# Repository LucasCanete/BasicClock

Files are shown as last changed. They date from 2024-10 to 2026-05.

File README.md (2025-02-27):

# BasicClock
Small atmega328p-based Clock displays the time, the temperature and humidity of the room.

## Table of Contents
1. [About the Project](#about-the-project)
2. [Project Status](#project-status)
3. [Getting Started](#getting-started)

## About the Project
Every Christmas I have to think hard what to give as a gift to my friends. As the Maker i am i decided to develop a device i could always give as a gift in Birthdays or Christmas when i dont come with any better idea. The device is a simple Clock with a big display and three buttons. The Clock lets the user see the time, temperature and humidity of the room. Additionally, the user can configure the time in case time changes or the person moves to a different timezone.

Besides from all this, i just wanted to try program different sensors with the Atmega328p using C++. I found it very convenient with the OOP so i might keep using it in the future.

Features:
- Visualization of current date, hour, temperature and humidity
- Configuration of date and hour
- USB-C port for UART communication
- Small design for being portable

## Project Status
Project is currently under development. Next Steps are the following:
- [x] Order Board from JLCPCB
- [ ] Order Stencil (i forgot it the first time)
- [ ] Solder SMD Components
- [ ] Test BME280
- [ ] Test RTC
- [ ] Test USB-C UART Communication
- [ ] Write driver for Display
- [ ] Finish writing the firmware

## Getting Started
Coming soon

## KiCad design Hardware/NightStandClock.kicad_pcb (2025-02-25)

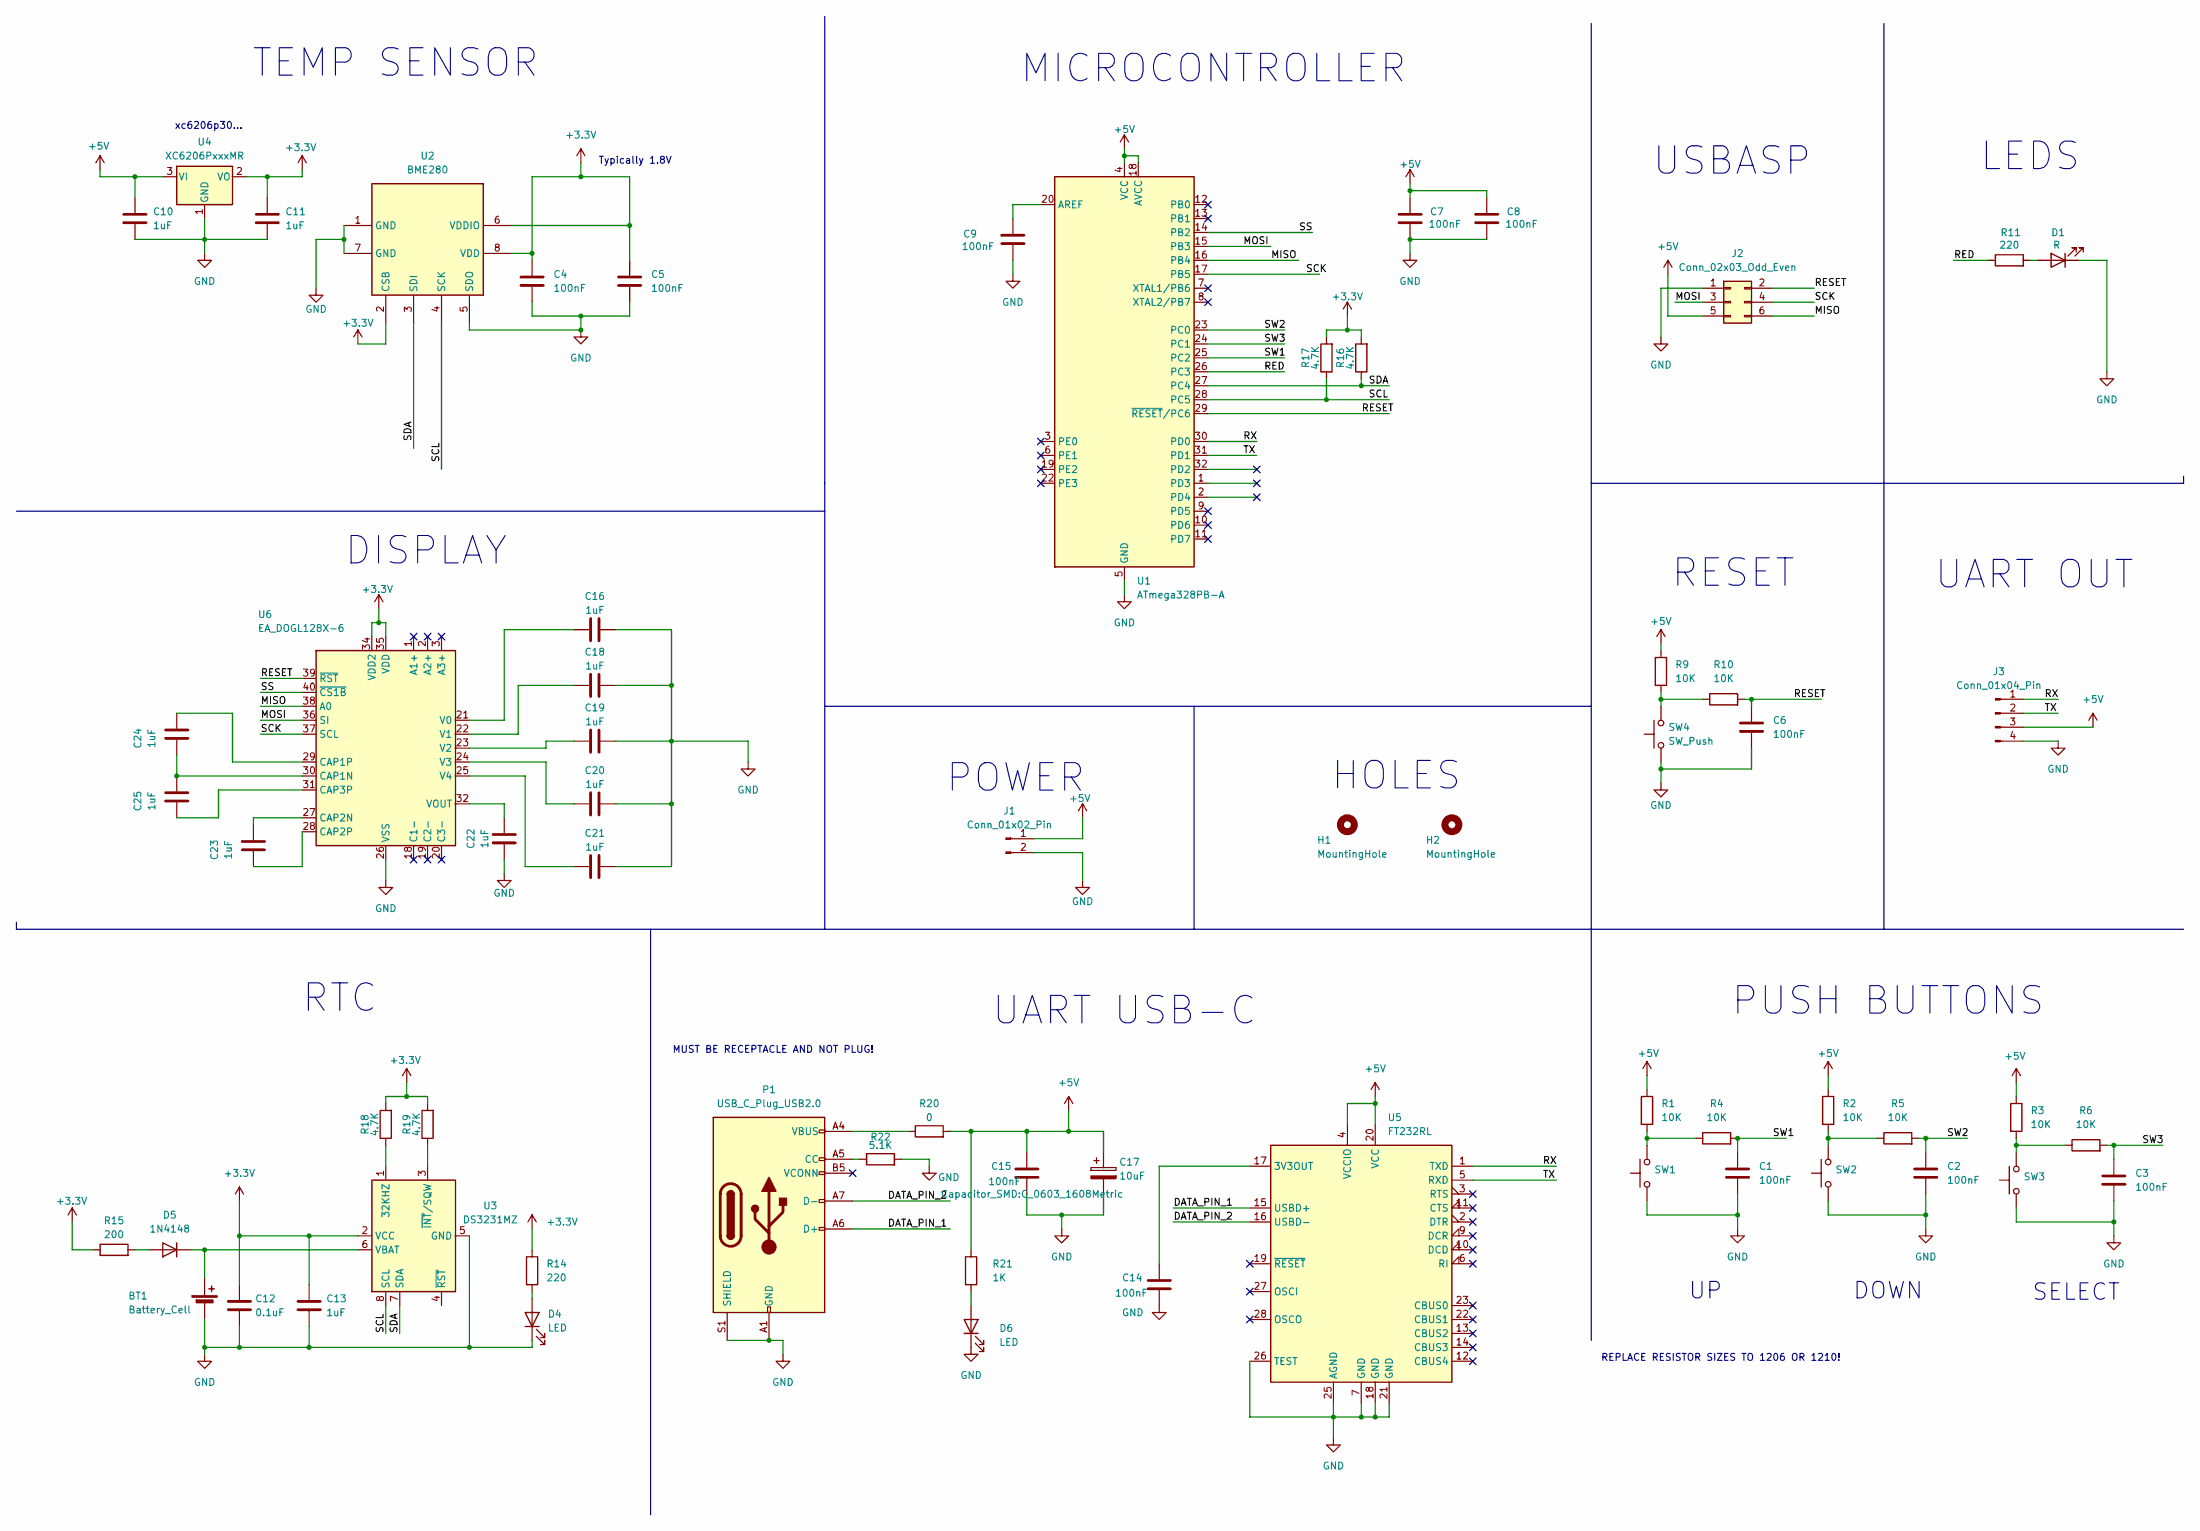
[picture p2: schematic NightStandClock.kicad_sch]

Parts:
BT1: Battery_Cell; BatteryHolder_MYOUNG_BS-07-A1BJ001_CR2032
C1, C2, C3, C4, C5, C6, C7, C8, C9, C14, C15: 100nF; C_0603_1608Metric
C10, C11, C13, C16, C18, C19, C20, C21, C22, C23, C24, C25: 1uF; C_0603_1608Metric
C12: 0.1uF; C_0603_1608Metric
C17: 10uF; CP_Radial_D4.0mm_P2.00mm
D1: R; LED_0603_1608Metric
D4, D6: LED; LED_0603_1608Metric
D5: 1N4148; D_0603_1608Metric
H1, H2: MountingHole; MountingHole_2.1mm
J1: Conn_01x02_Pin; JST_XH_B2B-XH-A_1x02_P2.50mm_Vertical
J2: Conn_02x03_Odd_Even; PinSocket_2x03_P2.54mm_Vertical
J3: Conn_01x04_Pin; PinHeader_1x04_P2.54mm_Vertical
P1: USB_C_Plug_USB2.0; USB_C_Receptacle_GCT_USB4105-xx-A_16P_TopMnt_Horizontal
R1, R2, R3, R4, R5, R6, R9, R10: 10K; R_0603_1608Metric
R11, R14: 220; R_0603_1608Metric
R15: 200; R_0603_1608Metric
R16, R17, R18, R19: 4.7K; R_0603_1608Metric
R20: 0; R_0603_1608Metric
R21: 1K; R_0603_1608Metric
R22: 5.1K; R_0603_1608Metric
SW1, SW2, SW3: SW_PUSH_1P1T_6x3.5mm_H4.3_APEM_MJTP1243
SW4: SW_Push; SW_PUSH_1P1T_6x3.5mm_H4.3_APEM_MJTP1243
U1: ATmega328PB-A; TQFP-32_7x7mm_P0.8mm
U2: BME280; Bosch_LGA-8_2.5x2.5mm_P0.65mm_ClockwisePinNumbering
U3: DS3231MZ; SOIC-8_3.9x4.9mm_P1.27mm
U4: XC6206PxxxMR; SOT-23
U5: FT232RL; SSOP-28_5.3x10.2mm_P0.65mm
U6: EA_DOGL128X-6; EA_DOGL128-6

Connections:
+3.3V: C4.1, C5.1, C11.1, C12.1, C13.1, R14.1, R15.1, R16.2, R17.2, R18.2, R19.2, U2.2 (CSB), U2.6 (VDDIO), U2.8 (VDD), U3.2 (VCC), U4.2 (VO), U6.34 (VDD2), U6.35 (VDD)
+5V: C7.1, C8.1, C10.1, C15.1, C17.1, J1.1, J2.5, J3.3, R1.1, R2.1, R3.1, R9.1, R20.2, R21.1, U1.4 (VCC), U1.18 (AVCC), U4.3 (VI), U5.4 (VCCIO), U5.20 (VCC)
/DATA_PIN_1: P1.A6 (D+), U5.15 (USBD+)
/DATA_PIN_2: P1.A7 (D-), U5.16 (USBD-)
/MISO: J2.6, U1.16 (PB4), U6.38 (A0)
/MOSI: J2.3, U1.15 (PB3), U6.36 (SI)
/RED: R11.1, U1.26 (PC3)
/RESET: C6.1, J2.2, R10.2, U1.29 (~RESET/PC6), U6.39 (~RST)
/RX: J3.1, U1.30 (PD0), U5.1 (TXD)
/SCK: J2.4, U1.17 (PB5), U6.37 (SCL)
/SCL: R17.1, U1.28 (PC5), U2.4 (SCK), U3.8 (SCL)
/SDA: R16.1, U1.27 (PC4), U2.3 (SDI), U3.7 (SDA)
/SS: U1.14 (PB2), U6.40 (~CS1B)
/SW1: C1.1, R4.2, U1.25 (PC2)
/SW2: C2.1, R5.2, U1.23 (PC0)
/SW3: C3.1, R6.2, U1.24 (PC1)
/TX: J3.2, U1.31 (PD1), U5.5 (RXD)
GND: BT1.2 (-), C1.2, C2.2, C3.2, C4.2, C5.2, C6.2, C7.2, C8.2, C9.2, C10.2, C11.2, C12.2, C13.2, C14.2, C15.2, C16.2, C17.2, C18.2, C19.2, C20.2, C21.2, C22.1, D1.1 (K), D4.1 (K), D6.1 (K), J1.2, J2.1, J3.4, P1.A1 (GND), P1.A12 (GND), P1.B1 (GND), P1.B12 (GND), P1.S1 (SHIELD), R22.2, SW1.1, SW2.1, SW3.1, SW4.1, U1.5 (GND), U1.21 (GND), U2.1 (GND), U2.5 (SDO), U2.7 (GND), U3.5 (GND), U4.1 (GND), U5.7 (GND), U5.18 (GND), U5.21 (GND), U5.25 (AGND), U5.26 (TEST), U6.26 (VSS), U6.33 (VSS)
unnamed: BT1.1 (+), D5.1 (K), U3.6 (VBAT)
unnamed: D1.2 (A), R11.2
unnamed: D4.2 (A), R14.2
unnamed: D5.2 (A), R15.2
unnamed: D6.2 (A), R21.2
unnamed: P1.A5 (CC), R22.1
unnamed: P1.A4 (VBUS), P1.A9 (VBUS), P1.B4 (VBUS), P1.B9 (VBUS), R20.1
unnamed: R1.2, R4.1, SW1.2
unnamed: R2.2, R5.1, SW2.2
unnamed: R3.2, R6.1, SW3.2
unnamed: R9.2, R10.1, SW4.2
unnamed: C9.1, U1.20 (AREF)
unnamed: R18.1, U3.1 (32KHZ)
unnamed: R19.1, U3.3 (~INT/SQW)
unnamed: C14.1, U5.17 (3V3OUT)
unnamed: C24.1, C25.2, U6.30 (CAP1N)
unnamed: C24.2, U6.29 (CAP1P)
unnamed: C23.2, U6.27 (CAP2N)
unnamed: C23.1, U6.28 (CAP2P)
unnamed: C25.1, U6.31 (CAP3P)
unnamed: C16.1, U6.21 (V0)
unnamed: C18.1, U6.22 (V1)
unnamed: C19.1, U6.23 (V2)
unnamed: C20.1, U6.24 (V3)
unnamed: C21.1, U6.25 (V4)
unnamed: C22.2, U6.32 (VOUT)

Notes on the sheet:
RESET
DISPLAY
REPLACE RESISTOR SIZES TO 1206 OR 1210!
Typically 1.8V
HOLES
UART USB-C
POWER
xc6206p30...
UART OUT
PUSH BUTTONS
DOWN
MUST BE RECEPTACLE AND NOT PLUG!
MICROCONTROLLER
TEMP SENSOR
SELECT
LEDS
USBASP
RTC

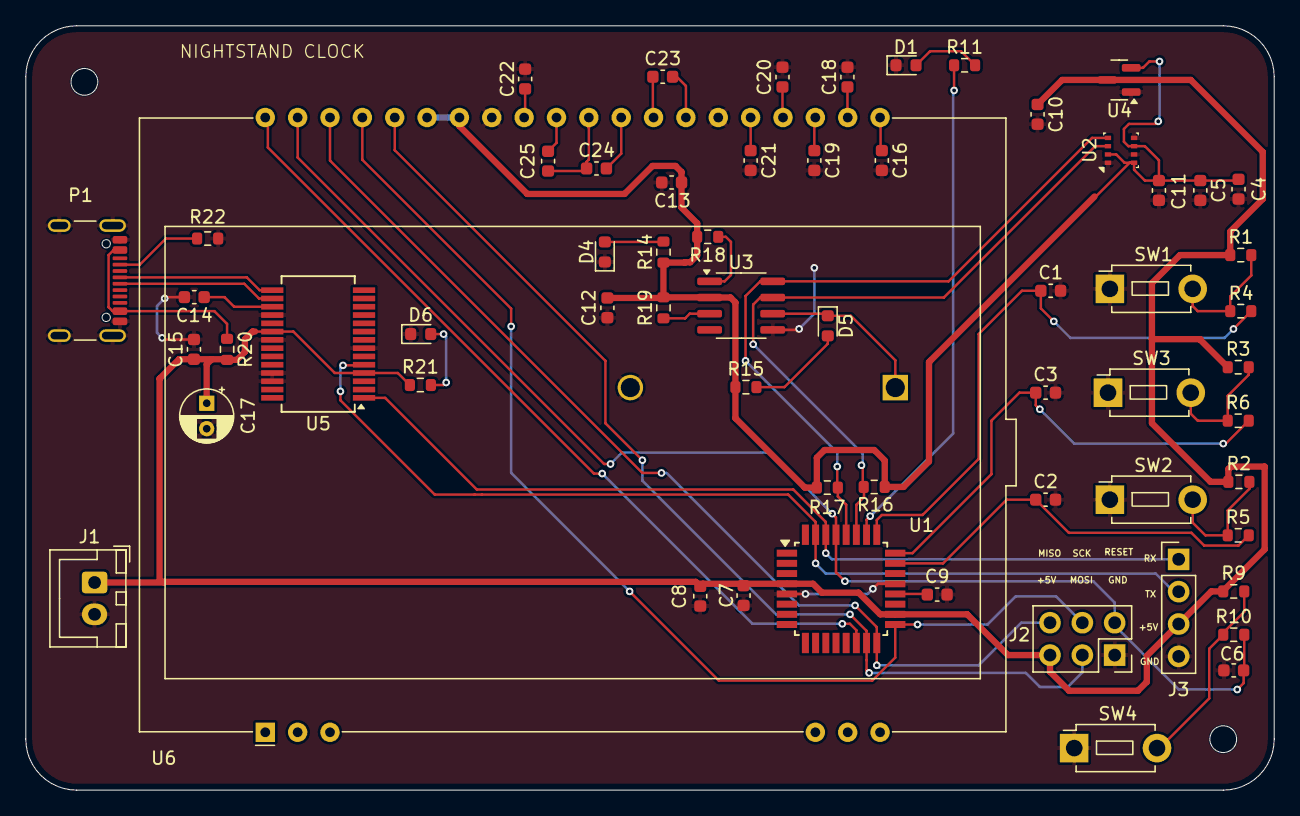
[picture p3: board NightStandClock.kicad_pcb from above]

Board: 2 copper layers, 98.0 x 60.0 mm, 64 parts (1 on the bottom side), 44 nets.

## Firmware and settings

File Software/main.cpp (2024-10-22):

/*

 Lucas Canete - September 2024
 */

#define F_CPU 1000000UL

#include <avr/io.h>
#include <util/delay.h>
#include <USART.h>
#include <BME280.h>
#include <RTC.h>
/*
 Button 1:PD2
 Button 2:PD3
 Button 3:PD4
 */

//Falling Edge PD2
ISR(INT0_vect){}
//Fallin Edge PD3
ISR(INT0_vect){}
typedef enum {IDLE,MEASURE,SHOW,CONFIG} state_t;

int main(){
    //Initialize PD2 and PD3 as interrupts
    EIMSK = (1<<INT1) | (1<<INT0):

    //Falling edge of PD2 and PD2 activates interrupts
    EICRA = (1<<ISC11) | (1<<ISC01);

    //Activate int. Flags from INT0 and INT1


    initUSART();

    BME280 bme(0x76);
    uint8_t id = bme.init();

    if (id == 0x60){
        printStringln("Success: Chip ID is 0x60!");
    }
    else {
        printStringln("Error: Chip not detected");
    }

    float temp, pressure;
    uint8_t humidity;

    DS3231 rtc;
    rtc.setSecond(0);
    rtc.setMinute(30);
    rtc.setHour(22);
    uint8_t hour, minute;

    state_t current_state = IDLE;
    DDRB |= (1<<PB1);

    while(1){
        PORTB ^= (1<<PB1);

        temp = bme.readTemperature();
        pressure = bme.readPressure()/100; //returns valid values
        humidity = bme.readHumidity(); //returns 0

        uint8_t second = rtc.second();
        minute = rtc. minute();
        hour = rtc.hour();

        printString("Hour: ");
        printByte(hour);
        printString(" Min: ");
        printByte(minute);
        printString(" Sec: ");
        printByte(second);
        printStringln(" ");

        printString("Temperature: ");
        printFloat(temp);
        //printByte((uint8_t)temp);
        printStringln(" ");

        printString("Pressure: ");
        printFloat(pressure);
        //printUInt16((uint16_t)pressure);
        //printByte((uint8_t)pressure);
        printStringln(" ");


        printString("Humidity: ");
        printByte((uint8_t)humidity);
        printStringln(" ");
        printStringln(" ");



         printStringln(" ");
        _delay_ms(1000);

        #if 0 
        switch(current_state){
            case IDLE:
                break;
            case MEASURE:

                minute = rtc. minute();
                hour = rtc.hour();

                temp = bme.readTemperature();
                pressure = bme.readPressure()/100;
                humidity = bme.readHumidity();

                break;
            case SHOW:
                break;
            case CONFIG:
                break;

        }
        #endif

    }
    return 0;
}

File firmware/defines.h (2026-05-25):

#ifndef DEFINES_H
#define DEFINES_H

//Board: XIAO ESP32S3
constexpr uint8_t ledPin = 21;

#define SCREEN_WIDTH 128 // OLED display width, in pixels
#define SCREEN_HEIGHT 32 // OLED display height, in pixels

#define OLED_RESET     -1 // Reset pin # (or -1 if sharing Arduino reset pin)
#define SCREEN_ADDRESS 0x3C ///< See datasheet for Address; 0x3D for 128x64, 0x3C for 128x32

#define BAR_X SCREEN_WIDTH*0.10/2
#define BAR_Y SCREEN_HEIGHT*0.80

#define VOLUME_BAR_HEIGHT 5
#define VOLUME_BAR_WIDTH SCREEN_WIDTH*0.90

#define ROTARY_DT 1
#define ROTARY_CLK 2


#endif

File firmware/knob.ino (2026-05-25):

#include <defines.h>
#include <volumeBar.h>
#include <Wire.h>
#include <Adafruit_GFX.h>
#include <Adafruit_SSD1306.h>
#include <logo.h>
#include <Rotary.h>

#include "USB.h"
#include "USBHIDConsumerControl.h"

Adafruit_SSD1306 display(SCREEN_WIDTH, SCREEN_HEIGHT, &Wire, OLED_RESET);
VolumeBar volumeBar (&display,BAR_X,BAR_Y,VOLUME_BAR_WIDTH,VOLUME_BAR_HEIGHT,WHITE);
RotaryEncoder rotary(ROTARY_DT,ROTARY_CLK);
USBHIDConsumerControl ConsumerControl;

uint8_t volume = 0;

void setup() {
  delay(3000);
  //ConsumerControl.begin();
  //USB.begin();
  pinMode(ledPin,OUTPUT);
  rotary.init();
  Serial.begin(115200);

  if(!display.begin(SSD1306_SWITCHCAPVCC, SCREEN_ADDRESS)) {
    Serial.println(F("SSD1306 allocation failed"));
    for(;;); // Don't proceed, loop forever
  }

  display.clearDisplay();

  display.drawBitmap(
    0,
    0,
    hs_logoBitmap,
    128,
    32,
    WHITE
);
  display.display();
  delay(3000);
  display.clearDisplay();


}

void loop() {

  Direction dir = rotary.getDirection();
  if(dir == Direction::CLOCKWISE && volume <= 95) {
    Serial.println("CLOCKWISE");
    volume+=5;
    //ConsumerControl.press(CONSUMER_CONTROL_VOLUME_INCREMENT);
    //ConsumerControl.release();
  }
  else if (dir == Direction::COUNTERCLOCKWISE && volume >= 5) {
    Serial.println("COUNTERCLOCKWISE");
    volume-=5;
    //ConsumerControl.press(CONSUMER_CONTROL_VOLUME_DECREMENT);
    //ConsumerControl.release();
    };

  //Display Rectangle Box Around the display
  display.drawRect(0,0, SCREEN_WIDTH, SCREEN_HEIGHT, WHITE);


  volumeBar.setValue(volume);
  volumeBar.draw();

  // Display Text
  display.setTextSize(3);       // Set text size
  display.setTextColor(WHITE);  // Set text color
  display.setCursor(SCREEN_WIDTH*0.35, SCREEN_HEIGHT*0.1);     // Set cursor position
  display.println(volume);
  display.display();  // Display the content on the screen
  //delay(10);
  display.clearDisplay();  // Clear the screen




}
